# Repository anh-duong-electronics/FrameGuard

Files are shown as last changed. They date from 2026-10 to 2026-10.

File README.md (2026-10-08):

# FrameGuard — Open Leakage Voltage Monitor for Factory Machines

A small, low-cost device that watches for dangerous AC voltage leaking onto the metal frames of industrial machines — and warns people before they touch it.

An open project by **Anh Duong Electronics Viet Nam** · 🌐 **Website: [anhduongelectronics.com](https://anhduongelectronics.com)**

Firmware for the STM32C031K6T6 (ARM Cortex-M0+), 1–4 monitoring channels, LCD + LED indication, RS-485 Modbus RTU output.

| Main board | PCB + LCD | 3D-printed enclosure |
|---|---|---|
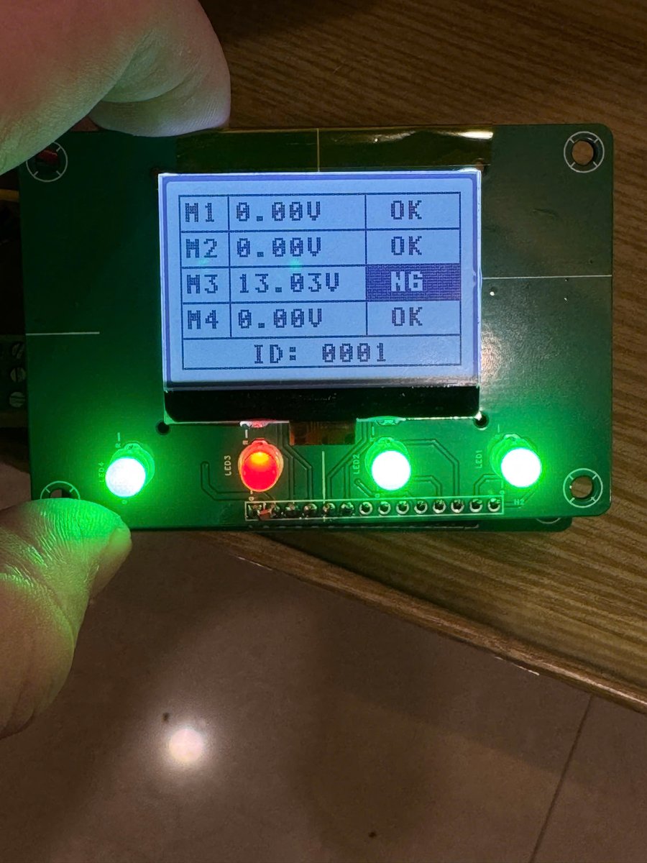
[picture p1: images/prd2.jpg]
Main board
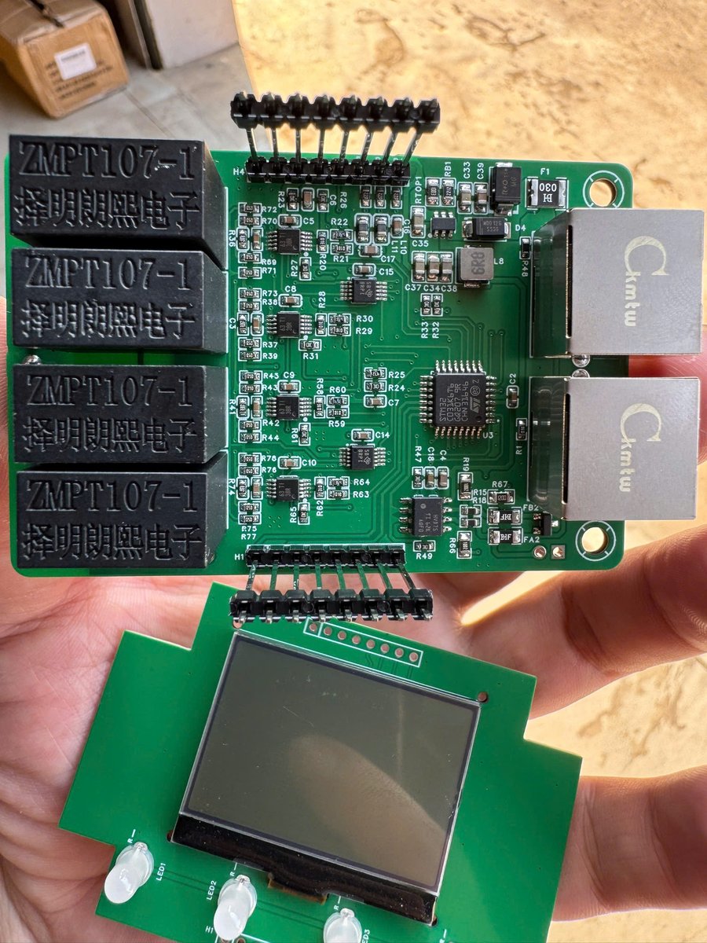
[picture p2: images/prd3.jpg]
PCB and LCD
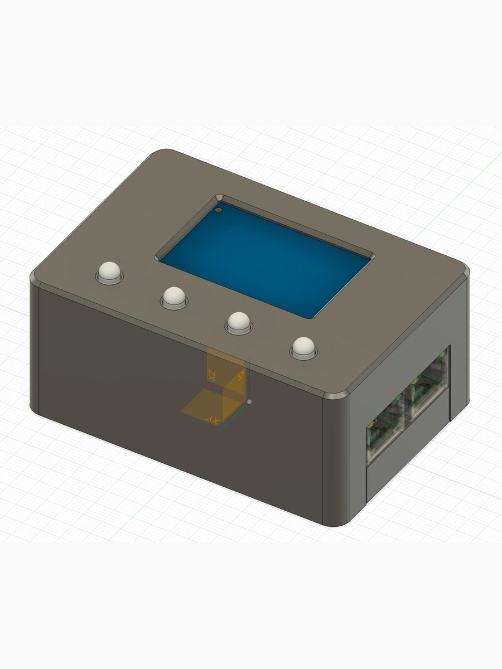
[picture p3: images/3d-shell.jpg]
Enclosure
|  |  |  |

---

## Why this project exists

Every day, millions of people work next to machines powered by mains electricity. When insulation ages, a cable is pinched, moisture gets in, or an earth connection quietly comes loose, the metal body of a machine can become live. Nothing looks different. The machine keeps running. The first person to notice may be the operator who touches it.

Electric shock in factories is preventable. Proper earthing, residual-current devices and regular inspection remain the foundation of electrical safety. But in many workplaces — especially small and medium factories — continuous monitoring of every machine frame is simply too expensive, so problems are found only during periodic checks, or after someone gets hurt.

This project started as a practical answer to that gap: **a simple box that sits on the production line, measures the voltage on each machine body continuously, and turns red the moment it becomes unsafe.** It also checks its own sensing wires, because a monitor with a broken wire that still shows "OK" is worse than no monitor at all.

I am sharing part of this work with the community because **worker safety should not depend on budget.** If this firmware helps one maintenance team find a leaking machine before a worker does, it has done its job.

### Who this is for

- Maintenance and electrical engineers who want an affordable early-warning layer on existing machines
- Makers and students learning embedded measurement, signal processing and industrial communication
- Small factories that cannot justify commercial monitoring systems for every workstation
- Anyone who wants to adapt, improve and share a safety tool

### What it does

- **Measures leakage voltage** on up to 4 machine frames, using true RMS so that distorted real-world signals (from inverters, filters, switching supplies) are not under-reported
- **Raises a clear alarm** per channel when voltage exceeds a configurable threshold — red LED and inverted "NG" on the LCD, visible from a distance
- **Detects broken or disconnected sensing wires** and reports them as a separate fault, so a silent failure is never mistaken for a safe reading
- **Reports to a central system** over RS-485 Modbus RTU, so a supervisor or SCADA/IoT gateway can watch many machines at once
- **Fails visibly**: watchdog-protected main loop, explicit INIT / ERR states, heartbeat counter on the bus

---

## ⚠️ Safety notice — please read

This is a **monitoring and early-warning aid**, not a protective device.

- It does **not** replace proper earthing, RCD/GFCI protection, insulation testing or the electrical safety regulations of your country.
- It has **not** been certified to any safety standard. Use it as an additional layer, never as the only one.
- Building, installing or connecting anything to mains-powered equipment must be done by **qualified personnel**, with the equipment isolated and following lock-out/tag-out procedures.
- The calibration table in this repository is a **placeholder**. Every build must be calibrated against a trusted true-RMS meter before it is relied on (see [Calibration](#calibration)).
- The software is provided "as is", without warranty of any kind (see [LICENSE](./LICENSE)).

If in doubt, treat every machine as live until proven otherwise.

---

## How it works (overview)

```
Machine frame ──► ZMPT107 voltage transformer ──► ADS1015 ADC (I2C) ──► STM32C031
                  (isolation + step-down)         (differential)        │
                                                                         ├─► True RMS + 50 Hz (Goertzel)
                                                                         ├─► Calibration table + per-channel K
                                                                         ├─► Threshold → OK / LEAK
                                                                         ├─► Wire check → WIRE_NG
                                                                         ▼
                                                    LCD 128×64 · LEDs · RS-485 Modbus RTU
```

- All filtering and RMS computation is done in software, so no precision analog filters are needed and the design adapts to 60 Hz grids by changing one constant.
- The device reports **true RMS** (fundamental + harmonics), matching what a true-RMS meter would show on a distorted leakage signal. The 50 Hz component is computed alongside it with the Goertzel algorithm.

See [docs/ac-measurement-algorithm.md](./docs/ac-measurement-algorithm.md) for a short explanation.

### Channel status

| Status | Meaning | LED |
|---|---|---|
| OK | Voltage below threshold, wire connected | Green |
| LEAK | Voltage above threshold | Red |
| WIRE_NG | Sensing wire broken or disconnected | Red, blinking |
| ERR | ADC / bus error | Off |
| INIT | Not yet confirmed | Off |
| DISABLED | Channel not in use (`qty=`) | Off |

---

## Hardware

- **MCU**: STM32C031K6T6 (ARM Cortex-M0+, LQFP32), 32 KB flash, 12 KB RAM, HSI 48 MHz ÷ 4 → 12 MHz
- **Sensing**: ZMPT107 voltage transformers + 2× ADS1015 12-bit ADC (I2C 0x48, 0x49), differential inputs
- **Display**: ST7567 128×64 LCD (SPI) + 4 bi-colour status LEDs
- **Field bus**: RS-485, Modbus RTU slave
- **Enclosure**: 3D-printable STL files in [`3d-shell/`](./3d-shell)
- **PCBA**: schematic, PCB layout and BOM are still under development and will be published as soon as the board has been verified to run reliably (see [Roadmap](#roadmap))

### Peripheral map

| Peripheral | Function | Pins | Notes |
|---|---|---|---|
| I2C1 | ADS1015 ADC | PA9 (SCL), PB9 (SDA) | 100 kHz |
| SPI1 | ST7567 LCD | PA1 (SCK), PA2 (MOSI), A0 = PA0, /RST = PA4, CS = GND | |
| ADC1, TIM1, GPIO | Wire check (`libwireprobe.a`) | PA5, PA7, PB0, PB1, PA8, PA15, PC6, PC15, PA6 | See `Core/Inc/wire_probe.h` |
| TIM3 | 1 µs timebase | — | Cortex-M0+ has no DWT cycle counter |
| USART1 | Modbus RTU slave | PC14 (TX), PB2 (RX), DE = PA12 | 9600 **8E1**, hardware DE, TX DMA |
| USART2 | Configuration commands (RX only) | PA3 (RX) | 115200 8N1, result shown on LCD |
| WWDG | Window watchdog | — | ~128–175 ms window |
| GPIO | 4 green/red LED pairs (active-low) | PB7/PB8, PB5/PB6, PB3/PB4, PA10/PA11 | |

---

## Getting started

### Requirements

- Arm GNU Toolchain (`arm-none-eabi-gcc`) — tested with GCC 13.2; on `PATH` or pass `make GCC_PATH=...`
- GNU Make
- SEGGER J-Link (or ST-Link / STM32CubeProgrammer)

### Build

```bash
make -j8
```

Output: `build/FrameGuard.elf` / `.hex` / `.bin` (~28.1 KB of the 30 KB application area).

- Default build is production (`DEBUG=0`).
- `make DEBUG=1` enables SEGGER RTT logging. It is built with link-time optimisation (`-flto`) so it fits the 30 KB budget (~26.8 KB).
- Run `make clean` when switching `DEBUG`.

### Flash (J-Link)

```bash
printf 'si 1\nspeed 3200\ndevice STM32C031K6\nconnect\nhalt\nloadfile build/FrameGuard.bin 0x08000000\nw4 0x40022000 0x00040600\nr\ng\nexit\n' | JLinkExe -nogui 1
```

The `w4 0x40022000 0x00040600` step clears `FLASH_ACR.EMPTY`. A blank STM32C0 latches this flag at power-up, and without clearing it every soft reset jumps into the system bootloader even though firmware is present. ST-Link / CubeProgrammer do not need this step.

### Debug logging (RTT)

Build with `make DEBUG=1`, then open JLinkRTTViewer (device `STM32C031K6`, SWD, 3200 kHz) or `JLinkRTTClient`. RTT `printf` has no `%f`; values are logged as integer millivolts.

---

## Configuration (USART2)

Send one line terminated by a newline at 115200 8N1. The result is shown on the LCD for 3 seconds and saved to flash.

| Command | Range | Purpose |
|---|---|---|
| `id=` | 1–9999 | Device ID (readable over Modbus) |
| `addr=` | 1–247 | Modbus slave address, effective immediately |
| `thr=` | 100–60000 mV | Leakage alarm threshold |
| `wire=` | 100–3000 | Wire-break detection threshold |
| `qty=` | 1–4 | Number of active channels |
| `v=` / `k1=`…`k4=` | 500–24000 mV | Per-channel calibration factor K |
| `config` | — | Show settings page on the LCD for 5 s |

## Modbus RTU

9600 bps, **8E1**, FC03 (read), FC04 (alias), FC06 (write registers 6 and 17). Standard poll: **FC03, address 1, quantity 17**.

Registers include per-channel voltage (0.01 V), per-channel status, alarm threshold, device ID, heartbeat and channel count. Full map: [docs/rs485-modbus-protocol.md](./docs/rs485-modbus-protocol.md).

## Calibration

The ZMPT107 response is not linear at low voltage, so the firmware converts readings through a multi-point table (`CAL[]` in `Core/Src/ads1015.c`) with piecewise-linear interpolation, then applies a per-channel factor K.

**The table shipped here is an illustrative linear placeholder.** To calibrate your build:

1. Build with `DEBUG=1` and connect RTT.
2. Apply known 50 Hz voltages across the range you care about, measured with a trusted true-RMS meter.
3. Record `vrms_total` for each level and replace the `CAL[]` entries (raw values must increase).
4. Rebuild with `DEBUG=0`, flash, then fine-tune each channel with `v=<mV>` while applying a known voltage.

---

## Repository layout

```
.
├── Core/
│   ├── Src/
│   │   ├── main.c            # Application, UART2 commands, Modbus register map
│   │   ├── ads1015.c         # ADS1015 driver, RMS + Goertzel, calibration table
│   │   ├── config_store.c    # Settings in the last flash page
│   │   ├── lcd_st7567.c      # ST7567 LCD driver
│   │   ├── modbus_rtu.c      # Portable Modbus RTU slave core (no HAL)
│   │   └── mb_port_usart1.c  # USART1 + DMA port for the Modbus core
│   ├── Inc/                  # Headers (wire_probe.h = wire-check API)
│   └── Lib/libwireprobe.a    # Wire-check implementation (prebuilt)
├── docs/                     # Technical notes
├── tools/                    # Python test scripts for Modbus and UART2
├── 3d-shell/                 # Enclosure STL files
└── images/
```

The wire-check implementation is distributed as a prebuilt library; everything else is open source.

## Documentation

- [AC measurement and Goertzel](./docs/ac-measurement-algorithm.md)
- [Modbus RTU protocol and register map](./docs/rs485-modbus-protocol.md)
- [System architecture](./docs/system-architecture.md)
- [ST7567 LCD notes](./docs/lcd-st7567-reference.md)
- [Test scripts](./tools/README.md)

## Development notes

- **CubeMX**: keep user code inside `/* USER CODE BEGIN/END */` blocks so regenerating from `FrameGuard.ioc` does not overwrite it.
- **Linker script**: `(READONLY)` was removed for GCC 10 compatibility; CubeMX adds it back on regeneration — remove it again or use GCC ≥ 11.
- **Watchdog**: the WWDG is always active; long operations must call `app_wwdg_kick()`.

---

## Roadmap

| Stage | Status |
|---|---|
| **Firmware** — measurement, alarms, wire check, Modbus RTU | ✅ Available in this repository |
| **3D-printed enclosure** | ✅ Available in [`3d-shell/`](./3d-shell) |
| **PCBA** — schematic, PCB layout, BOM | 🔧 In development — will be published as soon as the board has been tested and proven stable |
| **Community website** — a place to connect users, share installations, field reports and calibration data | 🗺️ Planned |
| **Real-time dashboard** — watch many machines and production lines live from one screen, with alarm history | 🗺️ Planned |

The goal is a complete, open safety kit: hardware anyone can build, firmware anyone can audit, and tools that let one person look after a whole factory floor.

---

## Contributing

Safety tools get better when more eyes look at them. Contributions are welcome, especially:

- Field reports: where you installed it, what you measured, what went wrong
- Calibration data and methods for other transformer types
- Translations of the documentation into other languages
- Hardware variants, enclosure improvements, 60 Hz validation
- Code review of the measurement and alarm logic

Please [open an issue](https://github.com/anh-duong-electronics/FrameGuard/issues) before large changes. When reporting a safety-related bug, describe the conditions clearly so others can reproduce and verify it.

## Authors

FrameGuard is developed and maintained by **Anh Duong Electronics Viet Nam** ([anhduongelectronics.com](https://anhduongelectronics.com)).

- **Lac Van Vien** — developer
- **My Nguyen** — developer

## License

The project source code is released under the [MIT License](./LICENSE), © 2026 Anh Duong Electronics Viet Nam.

Third-party components keep their original licenses:

- STM32C0xx HAL Driver (STMicroelectronics) — BSD-3-Clause, `Drivers/STM32C0xx_HAL_Driver/LICENSE.txt`
- CMSIS Device STM32C0xx (STMicroelectronics) — Apache-2.0, `Drivers/CMSIS/Device/ST/STM32C0xx/LICENSE.txt`
- CMSIS Core (Arm) — Apache-2.0, `Drivers/CMSIS/LICENSE.txt`
- SEGGER RTT — SEGGER BSD-style license, `Middlewares/Third_Party/SEGGER_RTT/LICENSE.md`

Project skeleton generated with STM32CubeMX 6.18.1 (STM32Cube FW_C0 V1.4.1).

---

*Built for the people on the factory floor. Stay safe.*

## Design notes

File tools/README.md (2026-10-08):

# Tools — Modbus RTU + UART2 config

Bench test scripts for the STM32 node (Modbus RTU slave + UART2 configuration commands). No HAL/STM32 dependency, only pyserial.

## Requirements

```bash
pip3 install pyserial
```

- USB-RS485: 9600 **8E1** (even parity)
- UART2 config: 115200 8N1, adapter TX → node RX (the node is RX-only; read results on the LCD or over Modbus)

## Scripts

| File | Purpose |
|---|---|
| `modbus_full_test.py` | FC03/04/06 test matrix: CRC, broadcast, bounds, slow feed, soak |
| `uart2_config_test.py` | Sends `id=`/`addr=`/`thr=`/`wire=`/`qty=` in one burst, verifies over Modbus |

```bash
python3 tools/modbus_full_test.py --port /dev/cu.usbserial-XXXX --addr 1
python3 tools/uart2_config_test.py --uart2 /dev/cu.usbmodemXXXX --rs485 /dev/cu.usbserial-XXXX --addr 1
```

FrameGuard register map (1-based): see [docs/rs485-modbus-protocol.md](../docs/rs485-modbus-protocol.md).

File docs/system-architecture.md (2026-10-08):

# System Architecture

## High-Level Block Diagram

```
┌─────────────────────────────────────────────────────────────────────┐
│                      STM32C031K6T6 (LQFP32)                         │
│                                                                       │
│  ┌───────────────────────────────────────────────────────────────┐  │
│  │           ARM Cortex-M0+ Core (12 MHz SYSCLK)               │  │
│  │  Flash: 32 KB  |  RAM: 12 KB  |  Stack: 0x400  |  Heap: 0x200  │
│  └───────────────────────────────────────────────────────────────┘  │
│                                                                       │
│  ┌──────────────────────────────────────────────────────────────┐   │
│  │                   Peripheral Interfaces                     │   │
│  │                                                              │   │
│  │  I2C1 (100 kHz, PA9/PB9)      ─→  ADS1015 ADC @ 0x48       │   │
│  │                                    (4 diff channels, 12-bit)  │   │
│  │  SPI1 (750 kHz, PA1/PA2)      ─→  ST7567 LCD 128×64 pixels  │   │
│  │                                    (A0=PA0, /RST=PA4, CS=GND)│   │
│  │  USART1 (9600 8E1, RS-485)    ─→  Modbus RTU slave (DE: PA12)│  │
│  │  USART2 (115200, RX-only PA3) ─→  UART2 config commands     │   │
│  │                                                              │   │
│  │  GPIO (9 outputs)             ─→  4× LED pairs + D0         │   │
│  │                                                              │   │
│  │  WWDG (~128–175 ms window)    ─→  Watchdog (active, guarded)│   │
│  │                                                              │   │
│  └──────────────────────────────────────────────────────────────┘   │
│                                                                       │
└─────────────────────────────────────────────────────────────────────┘
```

---

## Pinout Summary

### Power & Debug

| Pin | Type | Function | Notes |
|-----|---|---|---|
| VSS | GND | Ground (multiple pins) | - |
| VDD | +3.3V | Supply (multiple pins) | - |
| VDDA | +3.3V | Analog supply (ADC reference) | - |
| VREF+ | +3.3V | Internal reference (ADC) | - |
| PA13 | SWD | J-Link SWDIO (debug) | SWD @ 3.2 MHz confirmed working (HW v2, 2026-09-11). If attach fails, try 400 kHz. |
| PA14 | SWD | J-Link SWCLK (debug) | SWD @ 3.2 MHz confirmed working (HW v2, 2026-09-11). If attach fails, try 400 kHz. |

### Sensor & Measurement

| Pin | Port | Peripheral | Signal | Direction | Role | Notes |
|-----|---|---|---|---|---|---|
| PA9 | GPIOA | I2C1 | SCL | Bidirectional | ADS1015 ADC clock | 100 kHz, open-drain, 4.7 kΩ pull-up |
| PB9 | GPIOB | I2C1 | SDA | Bidirectional | ADS1015 ADC data | 100 kHz, open-drain, 4.7 kΩ pull-up |
| PA1 | GPIOA | SPI1 | SCLK | Output | ST7567 LCD clock | currently 750 kHz (lcd_init lowers the prescaler to /16) |
| PA2 | GPIOA | SPI1 | MOSI | Output | ST7567 LCD data | currently 750 kHz (lcd_init lowers the prescaler to /16) |
| PA0 | GPIOA | GPIO | A0 | Output | ST7567 LCD command/data | High=data, Low=command |
| PA4 | GPIOA | GPIO | LCD_RST | Output | ST7567 LCD hardware reset | lcd_init() configures PA4 once SPI is stable, hard-resets the LCD before the soft reset |

### Communication (RS-485)

| Pin | Port | Peripheral | Signal | Direction | Role |
|-----|---|---|---|---|---|
| PC14 | GPIOC | USART1 | TX | Output | RS-485 transmit (via PA12 DE) |
| PB2 | GPIOB | USART1 | RX | Input | RS-485 receive |
| PA12 | GPIOA | USART1 | DE | Output | Driver Enable (high = TX, low = RX) |

### USART2 configuration (RX-only)

| Pin | Port | Peripheral | Signal | Direction | Role |
|-----|---|---|---|---|---|
| PA3 | GPIOA | USART2 | RX | Input | Config commands (`id=`/`addr=`/`thr=`/`wire=`/`qty=`/`v=`/`kN=`/`config`), 115200 8N1, ISR ring. Feedback on LCD |

PA4 has been moved to GPIO for LCD /RST (see the Sensor & Measurement table).

### Status LEDs (4 green/red pairs, active-LOW, common anode)

| Pin | Port | Name | GPIO | Function | Status |
|-----|---|---|---|---|---|
| PB7 | GPIOB | L_GREEN1 | GPIO Output | Channel 1 green | Active |
| PB8 | GPIOB | L_RED1 | GPIO Output | Channel 1 red | Active |
| PB5 | GPIOB | L_GREEN2 | GPIO Output | Channel 2 green | Active |
| PB6 | GPIOB | L_RED2 | GPIO Output | Channel 2 red | Active |
| PB3 | GPIOB | L_GREEN3 | GPIO Output | Channel 3 green | Active |
| PB4 | GPIOB | L_RED3 | GPIO Output | Channel 3 red | Active |
| PA10 | GPIOA | L_GREEN4 | GPIO Output | Channel 4 green | Active |
| PA11 | GPIOA | L_RED4 | GPIO Output | Channel 4 red | Active |

Active-low LEDs (common anode), current-limited by external resistors. OK = green, leakage = red, wire broken = red heartbeat blink, ERR/INIT = off.

### Wire Check

Pins PA5, PA7, PB0, PB1 (ADC1), PA8 (TIM1_CH1) and PA15, PC6, PC15, PA6 (GPIO) are used by the
wire-break check. The implementation ships as a prebuilt library `Core/Lib/libwireprobe.a`;
see `Core/Inc/wire_probe.h` for the interface.

**TIM3**: free-running 1 µs timebase (SYSCLK 12 MHz, PSC=11, ARR=65535), replaces DWT→CYCCNT (not available on Cortex-M0+).

### Control Outputs

| Pin | Port | Name | GPIO | Notes |
|-----|---|---|---|---|
| PA0 | GPIOA | D0 | GPIO Output | ST7567 LCD A0 (command/data select) |

---

## Clock Tree

### System Clock Configuration

```
HSI (High Speed Internal Oscillator)
  │
  ├─ Frequency: 48 MHz (default, calibrated)
  │
  └─ RCC_HSI_DIV4 (prescaler /4)
       │
       └─ SYSCLK = 12 MHz
            │
            ├─ HCLK (AHB) = 12 MHz  (no divider)
            │
            ├─ PCLK1 (APB1) = 12 MHz (no divider)
            │
            └─ Peripherals:
                 I2C1: 12 MHz kernel clock (APB1)
                 SPI1: 12 MHz kernel clock (APB1)  → CubeMX prescaler /2 (6 Mbit/s); lcd_init lowers to /16 → 750 kHz
                 USART1: 12 MHz kernel clock (APB1) → 9600 bps
                 USART2: 12 MHz kernel clock (APB1) → 115200 bps
                 WWDG: 12 MHz kernel clock (APB1)  → PCLK1 / 4096 / 8 ≈ 366 Hz (~2.73 ms/count)
```

### Flash Latency

**FLASH_LATENCY_0** (0 wait cycles) — sufficient for 12 MHz operation.

### Recommended Frequency

At 12 MHz:
- Power consumption: Very low (~2–5 mA active, depending on peripherals)
- Timing budget: Adequate for sensor polling and RS-485 messaging
- Headroom: Available for future CPU-intensive tasks (DSP, FFT)

---

## Peripheral Details

### I2C1 Configuration

| Setting | Value | Notes |
|---|---|---|
| Mode | Standard (~100 kHz) | Timing: 0x00402D41 (optimized for 12 MHz) |
| Addressing | 7-bit | 8-bit addresses not used |
| Filters | Analog (enabled), Digital (0) | Noise filtering on SCL/SDA |
| Own Address | 0x00 | Slave mode not used (master only) |
| Pins | PA9 (SCL), PB9 (SDA) | Open-drain, pull-up required |

**Use case**: Read current-sensing transducers, ADCs, or other I2C sensors.

### SPI1 Configuration

| Setting | Value | Notes |
|---|---|---|
| Mode | Master | Slave mode not used |
| Direction | 2-line (MOSI+MISO) | TX-only intent in .ioc, but direction set to 2-line (conservative) |
| Data Size | 8-bit | Single byte transactions |
| Clock Polarity | 0 (CPOL=0) | Clock idles low |
| Clock Phase | 0 (CPHA=0) | Sampling on first edge |
| NSS | Soft (GPIO controlled) | No hardware NSS; PA15 or other GPIO pin managed in code |
| Baud Rate | CubeMX: PCLK1/2 = 6 Mbit/s; runtime: lcd_init sets /16 = 750 kHz | Slowed down during LCD debugging |
| Bit Order | MSB First | Standard SPI |

**Use case**: ST7567 LCD 128×64 (write-only; A0=PA0, /RST=PA4, CS tied to GND).

### USART1 (RS-485) Configuration

| Setting | Value | Notes |
|---|---|---|
| Baud Rate | 9600 bps | Industrial RS-485 |
| Data Bits | 8 | |
| Parity | **Even (8E1)** | Standard Modbus RTU |
| Stop Bits | 1 | |
| Mode | Asynchronous | Half-duplex, DE=PA12 |
| RS-485 Mode | Enabled | Hardware DEM, compatible with TX DMA |
| FIFO | Disabled | RX 1 byte RDR → ISR bare-register |
| Pins | PC14 (TX), PB2 (RX) | |

**Use case**: Modbus RTU slave (`modbus_rtu.c` + `mb_port_usart1.c`). FC03/04/06, map 1-based — [rs485-modbus-protocol.md](./rs485-modbus-protocol.md).

After `mb_init`: **no HAL UART TX API on USART1**. TX = DMA1 ch1 (DMAMUX req 51), polls TCIF. The RX ISR marks gaps ≥ 5 ms. NVIC USART1 priority 1.

### USART2 (Config Commands RX-only) Configuration

| Setting | Value | Notes |
|---|---|---|
| Baud Rate | 115200 bps | Configuration command interface |
| Data Bits | 8 | Standard byte format |
| Parity | None | No error detection |
| Stop Bits | 1 | Standard frame format |
| Mode | Receive only | PA3 RX; PA4 GPIO freed for LCD /RST |
| FIFO | Disabled | CubeMX default |
| Pins | PA3 (RX) | RX-only, no TX |

**Use case**: RX-only technician commands (`id=`/`addr=`/`thr=`/`wire=`/`qty=`/`v=`/`kN=`/`config`). `USART2_IRQHandler` → 32-byte ring (NVIC priority 2, below Modbus). `poll_serial()` only drains the ring + parses. LCD feedback for 3 s. Details: [rs485-modbus-protocol.md](./rs485-modbus-protocol.md).

### Window Watchdog (WWDG) Configuration

| Setting | Value | Notes |
|---|---|---|
| Prescaler | 8 (PCLK1 / 4096 / 8) | Watchdog clock = 12 MHz / 4096 / 8 ≈ 366 Hz (~2.73 ms/count) |
| Window | 80 (0x50) | Refresh allowed only when counter < 80 |
| Counter | 127 (0x7F) | Initial/reload value; reset fires when counter drops below 64 (0x40) |
| EWI (Early Wakeup) | Disabled | No interrupt before reset |
| Timeout | ~175 ms | (127 − 63) × 2.73 ms |
| Refresh window | ~131–175 ms after reload | Counter 79→64: window is open for ~44 ms |

**Critical caveats**:
- Code calls `app_wwdg_kick()` (main.c) everywhere: it only refreshes when the counter < Window and ignores early calls. Since the valid window is only ~44 ms wide, **two consecutive kick calls must be less than ~44 ms apart**, otherwise the first may be ignored (too early) and the next may already be past 175 ms → reset.
- Lesson learned: a blocking UART transmit of ~50 ms without kicking caused a reset on every measurement loop. Every long blocking operation (slow UART, LCD, delays) must be split into chunks with kicks in between; Modbus TX now uses background DMA.
- The RTT boot log prints `rst=... WWDG` when `RCC_FLAG_WWDGRST` is set, so watchdog resets are visible in the log.

---

## Memory Layout

### Flash (32 KB, 0x08000000–0x0800_7FFF)

```
0x08000000  ┌─────────────────────┐
            │  Vector Table       │  0x0C0 bytes (48 vectors)
            │  (.isr_vector)      │
0x080000C0  ├─────────────────────┤
            │                     │
            │  Code + Constants   │
            │  (.text)            │
            │  (CubeMX HAL ~28 KB)│
            │  (User code ~2–4 KB)│
            │                     │
0x0800_7FFF └─────────────────────┘  End of Flash
```

**Available for code**: 30 KB (page 15 = config_store). Production build (DEBUG=0) text+data **~28.1 KB**, RAM bss ~5.5 KB. DEBUG=1 (RTT, built with `-flto`) ~26.8 KB. Tight headroom (~1.9 KB in production).

### RAM (12 KB, 0x20000000–0x2000_2FFF)

```
0x20000000  ┌─────────────────────┐
            │  Initialized Data   │
            │  (.data)            │
            │  (HAL + User ~0.5 KB)
            ├─────────────────────┤  data_end
            │  Uninitialized Data │
            │  (.bss)             │
            │  (Global buffers, ~1 KB)
            ├─────────────────────┤  bss_end
            │  Heap (bottom-up)   │
            │  (Reserved 0x200 B) │  ← Growth direction
            ├─────────────────────┤  heap_base
            │  ...free...         │
            │                     │
            ├─────────────────────┤  stack_base
            │  Stack (top-down)   │
            │  (Reserved 0x400 B) │  ← Growth direction
0x2000_2FFF └─────────────────────┘  End of RAM (12 KB)
```

**Safe allocation**:
- `.bss` + `.data`: ~1.5 KB
- Stack: 0x400 bytes (1 KB)
- Heap: 0x200 bytes (0.5 KB)
- **Free for user buffers**: ~10 KB

---

## Interrupt Priority Model

All interrupts use **Cortex-M0+ NVIC** (16 priority levels, no sub-priorities in M0+).

### Default ISR Priorities (HAL configured)

| Handler | Vector | Priority | Type |
|---|---|---|---|
| Non-maskable Interrupt (NMI) | -14 | Highest | Fault |
| Hard Fault | -13 | Very High | Fault |
| System Tick (SysTick) | 15 | 0 (default) | Periodic |
| USART1 | 6 | 1 | Modbus RX ISR (mb_port_usart1) |
| USART2 | 7 | 2 | Config RX ISR (ring, below Modbus) |
| I2C1 (Events + Errors) | 23–24 | 0 (default) | Peripheral |
| SPI1 | 25 | 0 (default) | Peripheral |

USART1 (priority 1) preempts USART2 (priority 2) so config commands never cause lost Modbus bytes.

---

## Power Considerations

### Operating Supply

- **VDD**: +3.3 V (single supply)
- **VDDA**: +3.3 V (same as VDD, can be shared with filter capacitor)
- **Decoupling**: 100 nF (typical for 32-pin QFP)

### Current Consumption (Estimate)

At 12 MHz, running all peripherals:

| Component | Current (mA) |
|---|---|
| Core (M0+, 12 MHz) | ~2–3 |
| I2C (idle, pull-ups) | ~0.1–0.5 |
| SPI1 (idle) | <0.1 |
| USART1 (idle) | <0.1 |
| USART2 (idle) | <0.1 |
| GPIO (all outputs low) | <0.1 |
| **Total (idle)** | **~2–4 mA** |

**Note**: Actual power depends on:
- Sensor power draw (external)
- LED brightness (if enabled)
- Bus activity (RS-485 driver)
- Flash accesses

---

## System Initialization Sequence

```
Power-on Reset
    ↓
startup_stm32c031xx.s (Reset Handler)
    ↓
SystemInit() [system_stm32c0xx.c]
    └─ Set flash latency
    └─ Configure clock (HSI → 12 MHz)
    └─ Set NVIC priority defaults
    ↓
main()
    └─ HAL_Init()
         └─ Configure SysTick (1 ms tick)
         └─ Set default NVIC priorities
    └─ SystemClock_Config()  [already done, safety check]
    └─ MX_GPIO_Init()
    └─ MX_I2C1_Init()
    └─ MX_SPI1_Init()
    └─ MX_USART1_UART_Init()
    └─ MX_USART2_UART_Init()  [RXNEIE, NVIC prio 2]
    └─ MX_ADC1_Init()  [ADC1 sequencer, SamplingTimeCommon1 79.5 cycles]
    └─ MX_TIM1_Init()  [TIM1 PWM at PA8 for wire check]
    └─ MX_TIM3_Init()  [TIM3 1 µs timebase]
    └─ MX_WWDG_Init()
    └─ APP_LOG_INIT()  [SEGGER RTT init if DEBUG=1]
    └─ config_load()  [layout v4: id/addr/qty/thr/wire/K]
    └─ probe_set_open_mvpp(g_cfg.wire_mvpp)
    └─ mb_init()  [Modbus RTU, no HAL TX on USART1]
    └─ ads_probe() × 2  [probe ADS1015 @ 0x48, 0x49]
    └─ probe_init()  [wire check]
    └─ lcd_init()  [SPI + PA4 hard reset]
    ↓
Main Loop (~1 Hz per group)
    └─ for each channel 0..3: if i ≥ ch_count → LED off, clear data, skip
    └─ probe_measure() + probe_update()
    └─ ads_measure_channel(); vac = calibration_table × K[i]
    └─ mb_poll() between channels (hooks in ads1015 + main)
    └─ lcd_show_channels()  [disabled channels blank; 5 s config page after the config command]
    └─ poll_serial()  [drain the USART2 ring]
    └─ app_wwdg_kick()
    ↓
(Continues at ~1 Hz; WWDG fires reset if not refreshed ~131–175 ms)
```

---

## Flashing & Debugging

### J-Link Programming with FLASH_ACR.EMPTY Workaround

**Issue**: When programming a blank STM32C031 chip via J-Link, the MCU may fail to boot firmware after reset, instead jumping to the system bootloader (PC = 0x1FFF0CDE). Cause: FLASH_ACR.EMPTY flag is latched at power-on when flash is blank; soft reset (SYSRESETREQ) does not reload option bytes, so every reset—including HAL_Delay softresets—stays in bootloader.

**Solution**: After loading firmware via `loadfile`, issue J-Link command `w4 0x40022000 0x00040600` to clear the EMPTY flag. This writes the correct FLASH_ACR value (bits EMPTY=0, PRFTEN=0, DUF=1) before disconnecting.

```bash
JLinkExe -nogui <<EOF
si 1
speed 3200
device STM32C031K6
connect
halt
loadfile build/FrameGuard.bin 0x08000000
w4 0x40022000 0x00040600    # ← Clear FLASH_ACR.EMPTY before reset
r
g
exit
EOF
```

**Note**: ST-Link and CubeProgrammer do not exhibit this issue because they use hardware reset (NRST) instead of SYSRESETREQ, which automatically handles the flag reload.

**SWD Speed**: `speed 3200` (3.2 MHz) is stable for flashing and RTT on this board; if attach fails, drop to 400 kHz.

---

## External Connections

### ADS1015 ADC (I2C @ 0x48)

```
STM32C031K6T6 (PA9=SCL, PB9=SDA)
         │
    [I2C @ 100 kHz]
         │
   ┌─────┴─────┐
   │ ADS1015   │
   │ (ADDR=GND)│
   │ 12-bit    │
   │ 4-channel │
   └─────┬─────┘
         │
    [AIN0–AIN3: 2 differential channels from ZMPT107 transformers; second IC @ 0x49 (ADDR=VDD)]
```

**Note**: 4.7 kΩ pull-ups on SCL/SDA to 3.3V required.

### ST7567 LCD (SPI, currently 750 kHz)

```
STM32C031K6T6
  ├─ PA1 (SCLK) ──────────┐
  ├─ PA2 (MOSI) ──────────┤
  ├─ PA0 (A0)   ──────────├─ ST7567 LCD
  ├─ PA4 (/RST) ──────────┤  128×64 pixels
  └─ CS (GND)   ──────────┤  COG12864-14-1
                          │
                [V0–XV0, VG–VSS:]
                 0.1–1 µF X7R caps
                 (booster supply)
```

**Hardware changes (HW v2)**:
- LCD /RST pin now connected to GPIO PA4
- `lcd_init()` configures PA4 as output and hard-resets the LCD (~10 µs pulse) **after SPI is stable** (SCK/MOSI at defined levels)
- Why not NRST: if the LCD powers up before the MCU it sees a floating (undefined) SCK → byte slip. A self-configured PA4 GPIO reset guarantees the timing.
- The firmware also sends a soft reset (0xE2 command) in the init routine

**Hardware note (resolved)**: LCD V0 supply (booster capacitor voltage) was collapsing due to undersized booster caps. Fixed with 0.1–1 µF X7R C0G capacitors at V0–XV0 and VG–VSS.

### RS-485 Network (USART1)

```
┌───────────────────────────────────────┐
│  Central Monitoring System            │
│  (RS-485 Master)                      │
└───────────────────┬───────────────────┘
                    │
        ┌───────────┴──────────┐
        │   Twisted Pair (A, B)│
        │   (120 Ω terminator) │
        └───────────┬──────────┘
                    │
     [PA12 DE]  [PC14 TX/PB2 RX]
         │           │
    ┌────┴───────────┘
    │
STM32C031K6T6 (RS-485 Slave)
```

USART1 is **in use**: Modbus RTU slave. The master polls FC03 addr 1 qty 17; recommended timeout 500 ms over USB-RS485.

---

**For register-level details, consult the [STM32C031 Datasheet](https://www.st.com/en/microcontrollers/stm32c031k6.html).**  
**For AC measurement algorithm (Goertzel, calib, RMS), see [AC Measurement Algorithm](./ac-measurement-algorithm.md).**

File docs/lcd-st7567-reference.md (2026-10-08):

# LCD ST7567 Reference

Reference notes for the ST7567 128x64 COG LCD module, reusable in other STM32 projects.

## Panel

- **IC**: ST7567 (controller on glass)
- **Panel**: Xuyang COG12864-14-1, 1.9", 128x64 pixels, monochrome
- **Interface**: SPI (mode 0: CPOL=0, CPHA=0), MSB first
- **Supply**: 3.3 V logic, internal booster generates V0 for the LCD
- **Duty/Bias**: 1/65 duty, 1/9 bias (`CMD_BIAS_1_9 = 0xA2`)

## Hardware connections

| LCD pin | Function | Notes |
|---|---|---|
| SCK | SPI clock | SPI1_SCK |
| SDA/MOSI | SPI data | SPI1_MOSI |
| A0 | Command/data select | GPIO output: LOW = command, HIGH = data |
| /RST | Hardware reset | GPIO output: active low, 10 ms pulse |
| CS | Chip select | **Tied to GND** (always selected) |
| V0, XV0 | Booster output | Booster capacitor between the two pins |
| VG, VSS | Booster ground | Booster capacitor between the two pins |

### Booster capacitors (IMPORTANT)

V0–XV0 and VG–VSS need **X7R 0.1–1 µF** capacitors (ceramic, low ESR). The wrong capacitor causes LCD flicker:
- Wrong value or type → V0 unstable → the whole display flickers every ~200 ms
- SPI bursts interfering with the booster → V0 dips briefly → random flashes during fast updates
- Symptom: content is correct and not garbled, but blinks off and recovers by itself

**Diagnosis**: if a static test (no SPI after boot) still flickers → definitely the capacitors. If it only flickers during updates → marginal capacitors, SPI bursts make V0 dip.

## Driver configuration

```c
/* lcd_st7567.h */
#define LCD_WIDTH      128
#define LCD_HEIGHT     64
#define LCD_PAGES      (LCD_HEIGHT / 8)   /* 8 pages */
#define LCD_X_OFFSET   0                  /* DDRAM has 132 columns, panel starts at 0 */

#define LCD_CONTRAST   10       /* EV 0..63, EV=10 gives good contrast on this panel */
#define LCD_RR         0x25     /* Regulator ratio 5.5 (0x20..0x27 → 3.0..6.5) */
#define LCD_SEG_REMAP  0xA0     /* 0xA0 normal, 0xA1 mirror horizontal */
#define LCD_COM_DIR    0xC8     /* 0xC0 normal, 0xC8 mirror vertical */
```

## Initialisation sequence

```
1. Configure the /RST GPIO (output push-pull)
2. Hardware reset: /RST LOW 10 ms → HIGH 10 ms
3. Kick the WWDG (if used)
4. Soft reset (0xE2), delay 10 ms
5. Display OFF (0xAE)
6. Start line = 0 (0x40)
7. SEG remap (0xA0 or 0xA1)
8. COM direction (0xC0 or 0xC8)
9. Bias 1/9 (0xA2)
10. Display normal (0xA6, not inverted)
11. All pixels off (0xA4)
12. Power up booster → regulator → follower:
    - 0x2C, delay 50 ms, kick WWDG
    - 0x2E, delay 50 ms, kick WWDG
    - 0x2F, delay 10 ms, kick WWDG
13. Regulator ratio (LCD_RR)
14. EV set: 0x81, LCD_CONTRAST
15. Booster ratio: 0xF8, 0x00
16. Clear the framebuffer, update the display
17. Display ON (0xAF)
```

Total init time: ~140 ms (mostly the power-up sequence). With a WWDG (~131 ms window), kicks must be interleaved between delays.

## Framebuffer & rendering

- Framebuffer: `uint8_t fb[8][128]` — 8 pages × 128 columns = 1024 bytes
- Each page = 8 vertical pixels, LSB = top pixel
- Set pixel: `fb[y >> 3][x] |= (1u << (y & 7))`
- Clear pixel: `fb[y >> 3][x] &= ~(1u << (y & 7))`

### Updating the display

```c
void lcd_update_pages(uint8_t page0, uint8_t page1)
{
  for (page = page0; page <= page1; page++) {
    lcd_set_page_col(page, 0);     /* set page + column 0 */
    lcd_data_buf(fb[page], 128);   /* SPI transmit 128 bytes */
  }
}
```

- `lcd_update()` = update all 8 pages
- Partial updates (`lcd_update_pages(2, 5)`) reduce SPI traffic when only a middle region changes

### A0 settle time

CS is tied to GND, so there is no CS toggle between command and data. A0 must settle before the first SCLK edge:

```c
static void lcd_a0(GPIO_PinState s)
{
  lcd_spi_ready();                    /* wait for SPI to finish */
  HAL_GPIO_WritePin(A0_PORT, A0_PIN, s);
  for (volatile uint32_t i = 0; i < 48U; i++) {}  /* settle delay */
}
```

48 loop iterations @ 12 MHz ≈ 4 µs, enough for the ST7567.

## Font

- 5x7 font, column-major, LSB = top pixel
- ASCII 0x20..0x7E (space..tilde)
- Bold: each column is drawn as 2 adjacent pixels (col, col+1)
- Advance: 8 px per character (5 data + 1 bold + 2 spacing)

### Inverted text (white on black)

Used for inverted headers or blinking:

```c
void lcd_draw_char_inv(int x, int y, char c)
{
  /* Same as lcd_draw_char but lcd_set_pixel(..., 0) instead of 1 */
  /* Requires: the background area is already filled black */
}
```

Pattern: `lcd_fill_rect(x, y, w, h, 1)` then `lcd_draw_string_inv(...)`.

## Drawing primitives

| Function | Description |
|---|---|
| `lcd_clear()` | Clear the framebuffer (memset 0) |
| `lcd_update()` | Write the whole framebuffer to the display |
| `lcd_set_pixel(x, y, color)` | Set/clear one pixel |
| `lcd_draw_hline(x, y, w, color)` | Horizontal line |
| `lcd_draw_vline(x, y, h, color)` | Vertical line |
| `lcd_draw_rect(x, y, w, h, color)` | Rectangle outline |
| `lcd_fill_rect(x, y, w, h, color)` | Filled rectangle |
| `lcd_fill_circle(cx, cy, r, color)` | Filled circle |
| `lcd_draw_char(x, y, c)` | One character (bold, 8 px advance) |
| `lcd_draw_string(x, y, s)` | String |
| `lcd_draw_char_inv(x, y, c)` | Inverted character (white on black) |
| `lcd_draw_string_inv(x, y, s)` | Inverted string |
| `lcd_draw_uint(x, y, v)` | Unsigned integer |

## SPI speed

- CubeMX default: `SPI_BAUDRATEPRESCALER_2` → 6 MHz @ 12 MHz Fsys
- Debug prescaler in `lcd_init()`: `SPI_BAUDRATEPRESCALER_16` → 750 kHz
- Once stable, remove the override in `lcd_init()` to return to 6 MHz

## Debugging LCD flicker

1. **Static test**: draw once, then loop doing nothing → rules out software
2. **Counter test**: update every 1 s vs 100 ms → if flicker rate scales, SPI is triggering V0 dips
3. **Uptime counter**: if the counter keeps running through a flicker → the MCU did not reset → electrical issue
4. **Correct content after a flicker**: V0 sag (self-recovering), not SPI corruption (which would need DISPLAY_ON to recover)
5. **All-pixels-on test** (`0xA5`): bypasses RAM, tests the booster directly

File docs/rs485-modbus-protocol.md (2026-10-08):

# RS-485 Modbus RTU Protocol (FrameGuard node)

Single source of truth for the node firmware, the test scripts and the Modbus master. The map is **1-based**: addr 1 = VAC P1.

## Serial

| | |
|---|---|
| Baud rate | 9600 bps |
| Framing | **8E1** (even parity) |
| Slave address | 1–247, default 1; UART2 command `addr=` |
| Broadcast 0 | Strictly silent |
| Functions | **FC03** read; FC04 alias with the same data (optional); FC06 write single register (addr 6, 17) |
| Request | Exactly **8 bytes**. Frame ≠ 8 bytes → silent |

## Register map

`reg_count = 18`. Standard read: **FC03 addr 1 qty 17** (registers 1–17, including wire threshold + channel count).

| Addr | Name | Unit | Notes |
|---|---|---|---|
| 0 | reserved | — | reads 0 |
| 1–4 | VAC P1–P4 | 0.01 V | I2C error → `0xFFFF`; valid values clamp at `0xFFFE`. Disabled channel (`qty=`) → 0 |
| 5 | DEVICE_ID | — | 1–9999, device identifier |
| 6 | ALERT_THRESHOLD | mV | Active value in RAM. **Writable via FC06** (100–60000), not saved to flash |
| 7 | FW_HEARTBEAT | — | +1 per scan loop |
| 8–11 | CH_STATUS P1–P4 | enum | 0 INIT, 1 OK, 2 LEAK, 3 WIRE_NG, 4 ERR, **5 DISABLED** |
| 12–15 | WIRE_MVPP P1–P4 | — | wire-check reading (diagnostics). Disabled channel → 0 |
| 16 | WIRE_THRESHOLD | — | read-only; set with `wire=` (100–3000) |
| 17 | CH_COUNT | — | **Writable via FC06** (1–4), saved to flash — same as `qty=`. Channel i ≥ CH_COUNT: not measured, LED off, LCD blank, st=5 |

VAC < 0 ⇔ CH_STATUS = 4. VAC×1000 > ALERT_THRESHOLD ⇔ CH_STATUS = 2 (the same `is_leak()` used by LEDs/LCD).

FC06 to register 6 only changes RAM (a restart returns to the flash value). The persistent value is the UART2 `thr=` command (flash); a master that wants its own threshold should compare register 6 on every poll and re-write it with FC06 when it differs.

## Exceptions / silence

| Situation | Node |
|---|---|
| Unknown FC | exception 0x01 |
| addr/qty out of range, qty=0, FC06 addr ∉ {6, 17} | exception 0x02 |
| FC06 value out of range (reg 6: 100–60000; reg 17: 1–4) | exception 0x03 |
| Wrong address, bad CRC, frame ≠ 8 bytes, PE/FE/NE | silent |
| Request received > 150 ms ago and not yet answered | dropped silently |

## Timing

- One 8E1 character = 11 bits → ≈1.15 ms/byte. An FC03 17-register response = 39 bytes ≈ 45 ms.
- Frames complete **by length** (8 bytes). A gap ≥ 5 ms in the ISR marks a new frame boundary (USB-RS485 adapters often insert 1–16 ms gaps).
- Background TX DMA, hardware DE (DEM).
- Poll ≥ 1 s per node. USB-RS485 tool timeout: **500 ms** (measured Python+FTDI ~300 ms). Direct-UART master: 200 ms is enough unless the LCD stalls; 2 retries.
- The UART2 `config_save` flash erase takes ~22–40 ms: at most 1 request is lost, covered by master retries.

## UART2 — technician commands

USART2 **RX-only** on PA3, 115200 8N1. Feedback on the LCD for 3 s (inverted). Saved to flash immediately (magic in the last double-word). RX is interrupt-driven into a 32-byte ring, so a whole line can be sent in one burst (paste/script).

| Command | Range | Meaning |
|---|---|---|
| `id=` | 1–9999 | Device identifier (DEVICE_ID) |
| `addr=` | 1–247 | Modbus address, effective immediately |
| `thr=` | 100–60000 mV | Leakage threshold (flash + RAM) |
| `wire=` | 100–3000 | Wire-break detection threshold, shared by 4 channels |
| `qty=` | 1–4 | Number of channels in the machine group |
| `v=` | 500–24000 mV | Calibrate K on all enabled channels: K = V_ref / VAC_untrimmed, K ∈ 0.5..2.0 |
| `k1=`…`k4=` | 500–24000 mV | Calibrate K on one channel, same guard |
| `config` | (no argument) | Settings page on the LCD for 5 s |

There is no `show` command (no TX). Measured VAC = ADS calibration table × K[i], K defaults to 1.0.

Flashing firmware with config layout v4 (`CFG_MAGIC 0xAC05C1D4`) **erases older configs** — the technician must set them again.

## Example frames (slave 1)

```
FC03 read 17 regs:   01 03 00 01 00 11 D4 06
FC06 threshold 3000: 01 06 00 06 0B B8 6E 89   → echoed on success
FC06 channels = 2:   01 06 00 11 00 02 58 0E   → echoed on success, saved to flash
qty=125:             01 04 00 01 00 7D …       → exception 0x02
```

## Test scripts

See [tools/README.md](../tools/README.md).

- `tools/modbus_full_test.py` — 27 PASS / 0 FAIL on a real bus (1000 consecutive polls, 0 WWDG resets).
- `tools/uart2_config_test.py` — id/addr/thr/wire/qty PASS. Calibration `v=`/`kN=` needs an AC source and is not covered by the script.

## Threat model

The RS-485 bus is unauthenticated. Defences: strict CRC/length/range checks, no broadcast, FC06 only changes RAM; the master should check DEVICE_ID against an expected addr→id table.

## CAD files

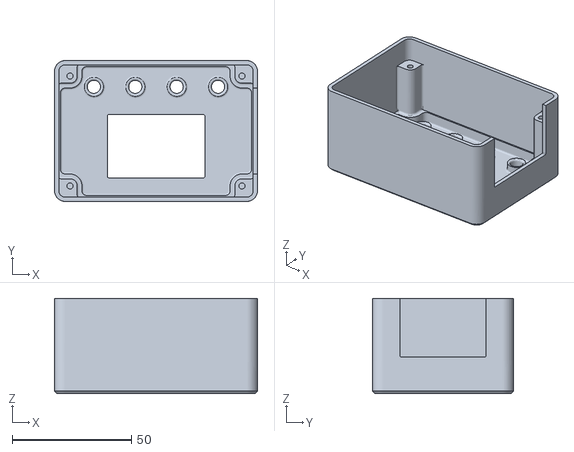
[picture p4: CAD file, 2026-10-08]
3d-shell/part2.stl
85.0 x 59.0 x 39.8

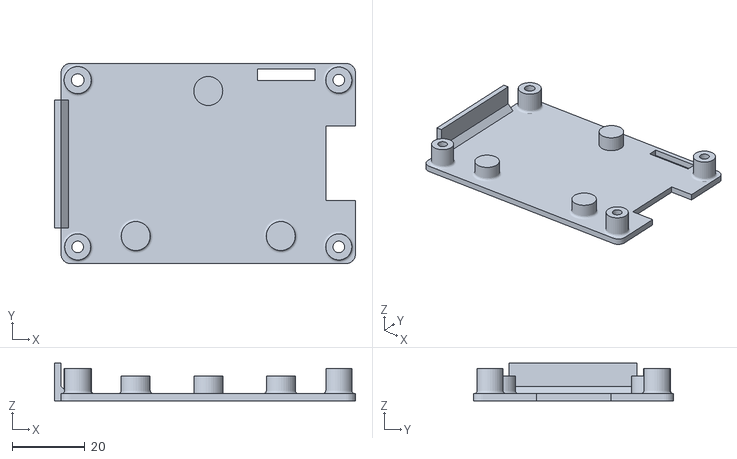
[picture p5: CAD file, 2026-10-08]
3d-shell/part1.stl
83.0 x 55.2 x 10.4

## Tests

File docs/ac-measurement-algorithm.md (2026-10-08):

# AC Measurement and the Goertzel Algorithm

A short description of how the device measures AC leakage voltage. Source code: `Core/Src/ads1015.c`.

## Measurement chain

```
AC leakage voltage
    │
    ▼
ZMPT107 (voltage transformer)  ← step-down, isolation
    │
    ▼
ADS1015 (ADC, I2C)             ← differential measurement, digitising
    │
    ▼
STM32 (software)               ← RMS, extract the 50 Hz component
    │
    ▼
Calibration table              ← convert to the actual voltage
    │
    ▼
LCD / LED / RS-485
```

The analog front end only steps down and digitises. All frequency filtering and RMS computation is done in
software, so no analog filter is needed, and moving to a 60 Hz grid only means changing one constant.

## Sampling

Each channel is sampled continuously over a short window containing several whole mains cycles.
The mean of the samples (the DC component, from ADC offset) is subtracted before processing.

## Two ways to compute RMS

| Value | Computed by | Meaning |
|---|---|---|
| Full-band RMS | square root of the mean of squared samples | 50 Hz + harmonics + noise, like a true-RMS meter |
| 50 Hz RMS | Goertzel algorithm | Only the component at the mains frequency |

The device reports leakage using **full-band RMS**. Real leakage voltages (through EMI filter capacitors,
inverters) are often distorted and rich in harmonics; using only 50 Hz would read lower than a true-RMS meter.
The 50 Hz RMS is still computed for reference.

## The Goertzel algorithm

Goertzel answers the question: "how large is the component at **one specific frequency** in this signal?"
without computing the whole spectrum like an FFT.

Idea: compare the signal with a reference 50 Hz sine wave. The 50 Hz component is in step with it and
accumulates into a large value; harmonics and noise are out of step and cancel themselves out.

Goertzel does this with a recursive loop using only a few state variables and no sine table, which suits
a RAM-constrained microcontroller such as the Cortex-M0+. The target frequency is recomputed from the actual
sample rate of each measurement, so the result does not drift when the I2C speed varies.

## Calibration

The ZMPT107 response is not linear at low voltage, so the firmware converts readings through a **multi-point
calibration table** (piecewise-linear interpolation) rather than a single scale factor.

Small differences between transformers are compensated by a **per-channel factor K**, stored in flash.
Set K by applying a reference voltage to the channels and sending `v=<mV>` (or `k1=`…`k4=`) over UART2;
the firmware computes and saves it.

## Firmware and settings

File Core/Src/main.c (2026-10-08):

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
/* Includes ------------------------------------------------------------------*/
#include "main.h"

/* USER CODE BEGIN Includes */
#include <string.h>
#include <stdbool.h>
#include "ads1015.h"
#include "config_store.h"
#include "lcd_st7567.h"
#include "app_debug.h"
#include "wire_probe.h"
#include "modbus_rtu.h"
#include "mb_port_usart1.h"
/* USER CODE END Includes */

/* USER CODE BEGIN PD */
#define VAC_ZERO_V          0.05f     /* V_AC below this is treated as 0 — less decimal noise on the LCD */
#define PROBE_SETTLE_MS     3         /* wait for the switch to return to measure position before reading ADS */
#define LED_ENABLE          1         /* 1 = status LEDs on, 0 = off */
#define PRINT_INTERVAL_MS   1000UL    /* LCD + RTT log update period */
#define RS485_OFFLINE_MS    10000UL
#define CFG_MSG_MS          3000UL    /* how long a config-command result stays on the LCD ID row */
#define MB_REG_COUNT        18        /* map 1-based: addr 1..17, addr 0 reserved — docs/rs485-modbus-protocol.md */
#define LCD_PAGE_INTERVAL   5000UL
/* USER CODE END PD */

ADC_HandleTypeDef hadc1;

I2C_HandleTypeDef hi2c1;

SPI_HandleTypeDef hspi1;

TIM_HandleTypeDef htim1;
TIM_HandleTypeDef htim3;

UART_HandleTypeDef huart1;
UART_HandleTypeDef huart2;

WWDG_HandleTypeDef hwwdg;

/* USER CODE BEGIN PV */
static app_config_t g_cfg = {
  .device_id = 1001, .modbus_addr = 1, .ch_count = ADS_NUM_CHANNELS, .alert_mv = 5000,
  .wire_mvpp = PROBE_OPEN_MVPP_DEFAULT, .k_factor = { 1.0f, 1.0f, 1.0f, 1.0f },
};

/* ACTIVE alarm threshold (mV). Boots from g_cfg.alert_mv; FC06 overrides it
 * at runtime (RAM-only — the persistent value is managed by the master/UART2). Every threshold
 * comparison must go through is_leak() — never compare directly, to avoid mixing V and mV. */
static uint16_t g_alert_mv = 5000;
static uint16_t mb_heartbeat = 0;

static uint32_t last_rs485_poll  = 0;
static bool     lcd_page         = false;
static uint32_t last_page_switch = 0;

static float   vac_ch[ADS_NUM_CHANNELS] = { 0 };
static float   raw_ch[ADS_NUM_CHANNELS] = { 0 };   /* vrms_total — used for table calibration */
static float   vac_uncal[ADS_NUM_CHANNELS] = { 0 }; /* VAC before factor K — source for v=/kN= calibration */

/* Per-channel calibration factor; old configs (previous layout) stored 0 → treated as 1.0 */
static float kf(int i)
{
  float k = g_cfg.k_factor[i];
  return (k > 0.0f) ? k : 1.0f;
}
static probe_state_t wire_ch[ADS_NUM_CHANNELS];     /* confirmed wire-check result */
static uint16_t      wire_mvpp[ADS_NUM_CHANNELS];   /* latest wire-check amplitude, diagnostics */

/* Per-channel verdict for LED/LCD/RS485. Fixed numeric codes, used on the wire. */
typedef enum {
  CH_INIT = 0,   /* wire not yet confirmed after startup */
  CH_OK,         /* wire connected, no leakage */
  CH_LEAK,       /* leakage (LCD "NG") */
  CH_WIRE_NG,    /* sensing wire broken / open */
  CH_ERR,        /* ADS1015 not responding */
  CH_DISABLED,   /* channel beyond the configured count (qty=) — not measured, LED off, LCD blank */
} ch_status_t;

/* A machine group has 1..4 channels (qty= command): only P1..Pn are active */
static bool ch_enabled(int i) { return i < g_cfg.ch_count; }
static bool    wwdg_started = false;

#if LED_ENABLE
static GPIO_TypeDef *const LED_G_PORT[ADS_NUM_CHANNELS] =
  { L_GREEN4_GPIO_Port, L_GREEN3_GPIO_Port, L_GREEN2_GPIO_Port, L_GREEN1_GPIO_Port };
static const uint16_t LED_G_PIN[ADS_NUM_CHANNELS] =
  { L_GREEN4_Pin, L_GREEN3_Pin, L_GREEN2_Pin, L_GREEN1_Pin };
static GPIO_TypeDef *const LED_R_PORT[ADS_NUM_CHANNELS] =
  { L_RED4_GPIO_Port, L_RED3_GPIO_Port, L_RED2_GPIO_Port, L_RED1_GPIO_Port };
static const uint16_t LED_R_PIN[ADS_NUM_CHANNELS] =
  { L_RED4_Pin, L_RED3_Pin, L_RED2_Pin, L_RED1_Pin };
/* Desired LED state — written by the main loop, read by the SysTick ISR to update outputs */
static volatile bool g_green_on[ADS_NUM_CHANNELS] = { 0 };
static volatile bool g_red_on[ADS_NUM_CHANNELS]   = { 0 };
static volatile bool g_red_hb[ADS_NUM_CHANNELS]   = { 0 };   /* red heartbeat blink: wire broken */
#endif
/* USER CODE END PV */

void SystemClock_Config(void);
static void MX_GPIO_Init(void);
static void MX_I2C1_Init(void);
static void MX_SPI1_Init(void);
static void MX_USART1_UART_Init(void);
static void MX_USART2_UART_Init(void);
static void MX_WWDG_Init(void);
static void MX_ADC1_Init(void);
static void MX_TIM1_Init(void);
static void MX_TIM3_Init(void);
/* USER CODE BEGIN PFP */
static void poll_serial(void);
/* USER CODE END PFP */

/* USER CODE BEGIN 0 */
static char     cfg_msg[21];
static uint32_t cfg_msg_until = 0;
#define CFG_PAGE_MS 5000u
static uint32_t cfg_page_until = 0;

static void cfg_show(const char *s)
{
  strncpy(cfg_msg, s, sizeof(cfg_msg) - 1);
  cfg_msg[sizeof(cfg_msg) - 1] = '\0';
  cfg_msg_until = HAL_GetTick() + CFG_MSG_MS;
}

/* Window watchdog: may only be refreshed once the counter has dropped below Window
 * (~131 ms after the previous reload); refreshing earlier also resets the MCU.
 * Call it liberally everywhere — it ignores calls made before the window opens. */
void app_wwdg_kick(void)
{
  if (!wwdg_started) return;
  if ((hwwdg.Instance->CR & WWDG_CR_T) < hwwdg.Init.Window)
    HAL_WWDG_Refresh(&hwwdg);
}

/* The ONLY threshold comparison point — LEDs/LCD/Modbus STATUS all go through here */
static bool is_leak(int i)
{
  return vac_ch[i] >= 0 && vac_ch[i] * 1000.0f > (float)g_alert_mv;
}

/* Leakage ranks above a broken wire: a measured leakage voltage means the wire is connected. */
static ch_status_t ch_status(int i)
{
  if (!ch_enabled(i))                   return CH_DISABLED;
  if (vac_ch[i] < 0)                    return CH_ERR;
  if (is_leak(i))                       return CH_LEAK;
  if (wire_ch[i] == PROBE_OPEN)         return CH_WIRE_NG;
  if (wire_ch[i] == PROBE_UNKNOWN)      return CH_INIT;
  return CH_OK;
}

/* LEDs share a common anode, active LOW: pin RESET (pulled low) = on.
 * OK: green; leakage: red; wire broken: red heartbeat blink; ERR/INIT: both off. */
static void set_machine_led(int i, ch_status_t st)
{
#if LED_ENABLE
  g_green_on[i] = (st == CH_OK);
  g_red_on[i]   = (st == CH_LEAK);
  g_red_hb[i]   = (st == CH_WIRE_NG);
#else
  (void)i; (void)st;
#endif
}

/* Called from SysTick_Handler (1 kHz): updates the status LEDs.
 * Active-low LEDs (common anode, resistor-limited): RESET = on, SET = off.
 * Linux-style heartbeat for the red blink when the wire is broken. */
void app_led_pwm_tick(void)
{
#if LED_ENABLE
  static uint16_t hb = 0;
  if (++hb >= 1000) hb = 0;
  bool hb_on = (hb < 70) || (hb >= 170 && hb < 240);
  for (int i = 0; i < ADS_NUM_CHANNELS; i++) {
    bool red = g_red_on[i] || (g_red_hb[i] && hb_on);
    HAL_GPIO_WritePin(LED_G_PORT[i], LED_G_PIN[i], g_green_on[i] ? GPIO_PIN_RESET : GPIO_PIN_SET);
    HAL_GPIO_WritePin(LED_R_PORT[i], LED_R_PIN[i], red             ? GPIO_PIN_RESET : GPIO_PIN_SET);
  }
#endif
}

void app_rs485_poll_received(void) { last_rs485_poll = HAL_GetTick(); }

static bool    blink_state = false;
static uint32_t last_blink  = 0;


/* Layout (no header): 4 data rows + 1 ID row
 *  y=0  ───── outer border top
 *  y=1..12   M1 row (12px content)
 *  y=13 ───── divider
 *  y=14..25  M2 row
 *  y=26 ───── divider
 *  y=27..38  M3 row
 *  y=39 ───── divider
 *  y=40..51  M4 row
 *  y=52 ───── divider (above ID)
 *  y=53..62  ID row (10px, same as spec v2)
 *  y=63 ───── outer border bottom
 */
/* Append "<label><number>" to b at position n, return the new position */
static int fmt_label_u(char *b, int n, const char *label, uint32_t v)
{
  while (*label) b[n++] = *label++;
  char t[6];
  int  c = 0;
  do { t[c++] = (char)('0' + v % 10); v /= 10; } while (v);
  while (c) b[n++] = t[--c];
  b[n] = '\0';
  return n;
}

/* Settings page ("config" command): only the configured values, 5 rows */
static void lcd_show_settings(void)
{
  char b[17];
  int  n;
  lcd_draw_rect(0, 0, 128, 64, 1);

  n = fmt_label_u(b, 0, "ID:", g_cfg.device_id);
  n = fmt_label_u(b, n, " RS:", g_cfg.modbus_addr);
  lcd_draw_string(4, 3, b);

  n = fmt_label_u(b, 0, "THR:", g_cfg.alert_mv);
  n = fmt_label_u(b, n, " Qty:", g_cfg.ch_count);
  lcd_draw_string(4, 15, b);

  fmt_label_u(b, 0, "WIRE:", g_cfg.wire_mvpp);
  lcd_draw_string(4, 27, b);

  /* K×1000 — "K1:1000 K2:1000" matches how the kN= command displays it */
  n = fmt_label_u(b, 0, "K1:", (uint32_t)(kf(0) * 1000.0f + 0.5f));
  n = fmt_label_u(b, n, " K2:", (uint32_t)(kf(1) * 1000.0f + 0.5f));
  lcd_draw_string(4, 39, b);

  n = fmt_label_u(b, 0, "K3:", (uint32_t)(kf(2) * 1000.0f + 0.5f));
  n = fmt_label_u(b, n, " K4:", (uint32_t)(kf(3) * 1000.0f + 0.5f));
  lcd_draw_string(4, 51, b);
}

static void lcd_show_channels(bool any_alert)
{
  char buf[16];
  int i;
  lcd_clear();

  uint32_t now = HAL_GetTick();
  if (now - last_blink >= 500) {
    last_blink = now;
    blink_state = !blink_state;
  }

  if ((int32_t)(cfg_page_until - now) > 0) {
    lcd_show_settings();
    lcd_update();
    return;
  }

  lcd_draw_rect(0, 0, 128, 64, 1);

  lcd_draw_hline(0, 13, 128, 1);
  lcd_draw_hline(0, 26, 128, 1);
  lcd_draw_hline(0, 39, 128, 1);
  lcd_draw_hline(0, 52, 128, 1);

  lcd_draw_vline(28, 0, 53, 1);
  lcd_draw_vline(88, 0, 53, 1);

  static const int row_y[]  = {1, 14, 27, 40};
  static const int row_ye[] = {12, 25, 38, 51};

  for (i = 0; i < ADS_NUM_CHANNELS; i++) {
    int cy = row_y[i];
    int ty = cy + 2;

    if (!ch_enabled(i)) continue;        /* disabled channel: leave the row blank */

    lcd_draw_char(7, ty, 'P');
    lcd_draw_char(15, ty, (char)('1' + i));

    ch_status_t st = ch_status(i);
    if (vac_ch[i] < 0) {
      lcd_draw_string(32, ty, "----");
      lcd_draw_string(98, ty, "ERR");
    } else if (st == CH_WIRE_NG) {
      /* Wire broken: do not print 0.00V (easily mistaken for "no leakage"); both cells show
       * evenly spaced blinking 2x2 dots: voltage cell 29..87 5 dots every 12 px, status cell 89..126 4 dots every 9 px */
      if (blink_state) {
        for (int dx = 34; dx <= 82; dx += 12) lcd_fill_rect(dx, cy + 5, 2, 2, 1);
        for (int dx = 94; dx <= 121; dx += 9) lcd_fill_rect(dx, cy + 5, 2, 2, 1);
      }
    } else {
      int32_t s = (int32_t)(vac_ch[i] * 100.0f + 0.5f);
      if (s > 9999) s = 9999;
      int32_t ip = s / 100, fp = s % 100;
      int n = 0;
      if (ip >= 10) buf[n++] = (char)('0' + ip / 10);
      buf[n++] = (char)('0' + ip % 10);
      buf[n++] = '.';
      buf[n++] = (char)('0' + fp / 10);
      buf[n++] = (char)('0' + fp % 10);
      buf[n] = '\0';
      lcd_draw_string(32, ty, buf);
      lcd_draw_char(32 + n * 8, ty, 'V');

      const char *txt = st == CH_LEAK ? "NG" : st == CH_INIT ? "..." : "OK";
      if (st == CH_LEAK && blink_state) {
        lcd_fill_rect(89, cy, 38, row_ye[i] - cy + 1, 1);
        lcd_draw_string_inv(98, ty, txt);
      } else {
        lcd_draw_string(98, ty, txt);
      }
    }
  }

  /* ID row — 2-page alternating display */
  {
    if (now - last_page_switch >= LCD_PAGE_INTERVAL) {
      lcd_page = !lcd_page;
      last_page_switch = now;
    }

    if ((int32_t)(cfg_msg_until - now) > 0) {
      /* Config-command feedback, inverted to stand out, centred */
      int n = (int)strlen(cfg_msg);
      lcd_fill_rect(1, 53, 126, 10, 1);
      if (n <= 16) {
        lcd_draw_string_inv(64 - n * 4, 55, cfg_msg);
      } else {
        /* Long strings (5-command usage = 20 chars): 5 px glyphs drawn at 6 px pitch → 120 px */
        int x = 64 - n * 3;
        for (int k = 0; k < n; k++, x += 6) lcd_draw_char_inv(x, 55, cfg_msg[k]);
      }
    } else
    if (!lcd_page) {
      /* Page 1: ID:1001-RS:001 (14 chars, 112px, x=8) */
      uint16_t id = g_cfg.device_id;
      buf[0]  = 'I'; buf[1] = 'D';
      buf[2]  = blink_state ? ':' : ' ';
      buf[3]  = (char)('0' + (id / 1000) % 10);
      buf[4]  = (char)('0' + (id / 100) % 10);
      buf[5]  = (char)('0' + (id / 10) % 10);
      buf[6]  = (char)('0' + id % 10);
      buf[7]  = '-';
      buf[8]  = 'R'; buf[9] = 'S'; buf[10] = ':';
      buf[11] = (char)('0' + (g_cfg.modbus_addr / 100) % 10);
      buf[12] = (char)('0' + (g_cfg.modbus_addr / 10) % 10);
      buf[13] = (char)('0' + g_cfg.modbus_addr % 10);
      buf[14] = '\0';
      lcd_draw_string(8, 55, buf);
    } else {
      /* Page 2: LINK OK or OFFLINE M:SS */
      uint32_t elapsed = now - last_rs485_poll;
      bool offline = (elapsed > RS485_OFFLINE_MS);

      if (offline) {
        uint32_t secs = elapsed / 1000;
        uint32_t mm = secs / 60; if (mm > 9) mm = 9;
        uint32_t ss = secs % 60;
        buf[0] = 'O'; buf[1] = 'F'; buf[2] = 'F';
        buf[3] = 'L'; buf[4] = 'I'; buf[5] = 'N'; buf[6] = 'E'; buf[7] = ' ';
        buf[8] = (char)('0' + mm);
        buf[9] = ':';
        buf[10] = (char)('0' + ss / 10);
        buf[11] = (char)('0' + ss % 10);
        buf[12] = '\0';
        /* 12 chars = 96px → x=16 */
        lcd_fill_rect(1, 53, 126, 10, 1);
        lcd_draw_string_inv(16, 55, buf);
      } else {
        /* 7 chars = 56px → x=36 */
        lcd_draw_string(36, 55, "LINK OK");
      }
    }
  }

  (void)any_alert;
  lcd_update();
}

/* ---- Modbus RTU slave: 1-based register map, addr = channel number for clarity
 * (docs/rs485-modbus-protocol.md). Each channel's state is read from CH_STATUS —
 * there is no combined bitmap (it duplicated CH_STATUS). ----
 *  0    reserved (reads 0)
 *  1–4  V_AC channels P1–P4 (unit 0.01 V — matches LCD X.XX; I2C error → 0xFFFF, valid values clamp at 0xFFFE)
 *  5    DEVICE_ID                    6  ALERT_THRESHOLD mV (FC06 ghi, RAM-only)
 *  7    FW_HEARTBEAT                 8–11  CH_STATUS channels P1–P4 (ch_status_t)
 *  12–15 WIRE_MVPP channels P1–P4 (wire-check amplitude)
 *  16   WIRE_THRESHOLD (wire-break threshold shared by 4 channels, read-only)
 *  17   CH_COUNT 1..4 (channels in the group, writable via FC06 — like qty=, saved to flash;
 *       disabled channel: VAC=0, CH_STATUS=5, WIRE_MVPP=0) */
static uint16_t mb_app_reg_read(uint16_t addr)
{
  switch (addr) {
  case 1: case 2: case 3: case 4: {
    int i = addr - 1;
    if (!ch_enabled(i)) return 0;                  /* disabled channel (qty=) — CH_STATUS = 5 */
    if (vac_ch[i] < 0) return 0xFFFF;              /* I2C error — before any conversion */
    uint32_t cv = (uint32_t)(vac_ch[i] * 100.0f + 0.5f);   /* 0.01 V/LSB */
    return (cv > 0xFFFE) ? 0xFFFE : (uint16_t)cv;
  }
  case 5: return g_cfg.device_id;
  case 6: return g_alert_mv;
  case 7: return mb_heartbeat;
  case 8: case 9: case 10: case 11:
    return (uint16_t)ch_status(addr - 8);
  case 12: case 13: case 14: case 15:
    return wire_mvpp[addr - 12];
  case 16: return g_cfg.wire_mvpp;                 /* wire-break threshold (read-only; set with wire=) */
  case 17: return g_cfg.ch_count;                  /* channels in the group (qty= command) */
  default: return 0;                               /* addr 0 reserved; the core rejects addr ≥ MB_REG_COUNT */
  }
}

static void cfg_save_show(const char *label, uint32_t v)
{
  app_wwdg_kick();
  bool saved = config_save(&g_cfg);
  app_wwdg_kick();
  char m[20];
  int  n = 0;
  while (label[n]) { m[n] = label[n]; n++; }
  char tmp[6];
  int  t = 0;
  do { tmp[t++] = (char)('0' + v % 10); v /= 10; } while (v);
  while (t) m[n++] = tmp[--t];
  m[n] = '\0';
  strcat(m, saved ? " SAVED" : " FLASH!");
  cfg_show(m);
}

/* FC06 can write 2 registers:
 *  - 6  ALERT_THRESHOLD: RAM-only — the persistent value lives in flash (thr= command);
 *       a master that wants its own threshold re-writes it on every poll
 *  - 17 CH_COUNT: like the qty= UART2 command — saved to flash, applied on the next scan */
static mb_wr_result_t mb_app_reg_write(uint16_t addr, uint16_t val)
{
  switch (addr) {
  case 6:
    if (val < 100 || val > 60000) return MB_WR_BAD_VALUE;
    g_alert_mv = val;
    return MB_WR_OK;
  case 17:
    if (val < 1 || val > ADS_NUM_CHANNELS) return MB_WR_BAD_VALUE;
    g_cfg.ch_count = (uint8_t)val;       /* next scan: channels > val are skipped, data cleared */
    cfg_save_show("QTY:", val);          /* write flash + LCD feedback, same path as qty= */
    return MB_WR_OK;
  default:
    return MB_WR_BAD_ADDR;
  }
}

static const mb_port_t MB_PORT = {
  .get_tick_ms = HAL_GetTick,
  .tx_start    = mb_port_usart1_tx_start,
  .tx_busy     = mb_port_usart1_tx_busy,
  .reg_read    = mb_app_reg_read,
  .reg_write   = mb_app_reg_write,
  .on_reply_ok = app_rs485_poll_received,
};

void app_comm_poll(void) {
  mb_poll();
}

/* ---- Config commands over USART2 RX (no TX — result shown on the LCD for 3 s):
 * id=<1..9999> | addr=<1..247> | thr=<100..60000> (mV) | wire=<100..3000> (mVpp)
 * | qty=<1..4> (channel count) | v=<500..24000> (reference mV being applied → calibrate K on all 4 channels)
 * | k1=..k4=<500..24000> (calibrate K on one channel). Saved to flash immediately.
 * | config (no argument): show the settings page for 5 s. ---- */

/* Case-insensitive prefix match; returns a pointer past the prefix or NULL */
static const char *cmd_prefix(const char *p, const char *kw)
{
  while (*kw) {
    char c = *p, k = *kw;
    if (c >= 'A' && c <= 'Z') c = (char)(c - 'A' + 'a');
    if (c != k) return NULL;
    p++; kw++;
  }
  return p;
}

/* Parse a decimal number; -1 if empty or containing invalid characters */
static int32_t cmd_num(const char *d)
{
  if (*d < '0' || *d > '9') return -1;
  int32_t v = 0;
  for (; *d >= '0' && *d <= '9'; d++) {
    v = v * 10 + (*d - '0');
    if (v > 100000) return -1;
  }
  return (*d == '\0') ? v : -1;
}
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
int main(void)
{

  /* MCU Configuration--------------------------------------------------------*/

  /* Reset of all peripherals, Initializes the Flash interface and the Systick. */
  HAL_Init();

  /* Configure the system clock */
  SystemClock_Config();

  /* Initialize all configured peripherals */
  MX_GPIO_Init();
  MX_I2C1_Init();
  MX_SPI1_Init();
  MX_USART1_UART_Init();
  MX_USART2_UART_Init();
  MX_WWDG_Init();
  MX_ADC1_Init();
  MX_TIM1_Init();
  MX_TIM3_Init();
  /* USER CODE BEGIN 2 */
  APP_LOG_INIT();
#if APP_DEBUG
  /* J-Link halts the core (flashing, RTT attach) but the WWDG keeps counting → spurious WWDG reset.
   * Freeze the WWDG while the core is halted; not needed in production. */
  __HAL_RCC_DBGMCU_CLK_ENABLE();
  __HAL_DBGMCU_FREEZE_WWDG();
#endif
  wwdg_started = true;

  /* Load config from flash (if present); V conversion uses the static calibration table in ads1015.c */
  bool cfg_loaded = config_load(&g_cfg);
  g_alert_mv = g_cfg.alert_mv;
  probe_set_open_mvpp(g_cfg.wire_mvpp);

  /* Modbus RTU slave on USART1: core + bare-register port.
   * From here on, no HAL UART TX API may be used on huart1 (one UART, one owner). */
  mb_init(&MB_PORT, g_cfg.modbus_addr, MB_REG_COUNT);
  mb_port_usart1_init();

  APP_LOG("[boot] id=%u addr=%u thr=%umV cfg=%s rst=%s%s%s%s\r\n",
          g_cfg.device_id, g_cfg.modbus_addr, g_alert_mv, cfg_loaded ? "flash" : "defaults",
          __HAL_RCC_GET_FLAG(RCC_FLAG_PWRRST)  ? "POR "  : "",
          __HAL_RCC_GET_FLAG(RCC_FLAG_PINRST)  ? "PIN "  : "",
          __HAL_RCC_GET_FLAG(RCC_FLAG_SFTRST)  ? "SFT "  : "",
          __HAL_RCC_GET_FLAG(RCC_FLAG_WWDGRST) ? "WWDG " : "");
  __HAL_RCC_CLEAR_RESET_FLAGS();

  lcd_init();
  app_wwdg_kick();
  APP_LOG("[boot] lcd_init ok\r\n");
  probe_init();
  app_wwdg_kick();
  /* USER CODE END 2 */

  /* Infinite loop */
  /* USER CODE BEGIN WHILE */
  while (1)
  {
    /* USER CODE END WHILE */

    /* USER CODE BEGIN 3 */
    mb_poll();
    static uint32_t last_print = 0;
    bool any_alert = false;
    ads_meas_t m;

    for (int i = 0; i < ADS_NUM_CHANNELS; i++) {
      poll_serial();
      mb_poll();
      app_wwdg_kick();

      if (!ch_enabled(i)) {
        /* Disabled channel: clear old data (qty= changed at runtime), LED off, no measurement */
        vac_ch[i] = 0.0f; raw_ch[i] = 0.0f; vac_uncal[i] = 0.0f;
        wire_ch[i] = PROBE_UNKNOWN; wire_mvpp[i] = 0;
        set_machine_led(i, CH_DISABLED);
        continue;
      }

      /* Check the wire before every measurement, regardless of the previous result. */
      probe_result_t pr;
      if (probe_measure(i, &pr)) {
        wire_ch[i]   = probe_update(i, &pr);
        wire_mvpp[i] = pr.mvpp;
      } else {
        APP_LOG("[probe] P%d ADC error\r\n", i + 1);
      }
      HAL_Delay(PROBE_SETTLE_MS);
      app_wwdg_kick();

      bool ok = ads_measure_channel(&hi2c1, i, &m);
      vac_uncal[i] = ok ? m.vac : 0.0f;
      vac_ch[i] = ok ? m.vac * kf(i) : -1.0f;   /* -1 = IC not responding */
      raw_ch[i] = ok ? m.vrms_total : 0.0f;
      if (ok && vac_ch[i] < VAC_ZERO_V) vac_ch[i] = 0.0f;
      if (!ok) APP_LOG("[i2c] P%d not responding\r\n", i + 1);


      ch_status_t st = ch_status(i);
      if (st == CH_LEAK || st == CH_WIRE_NG) any_alert = true;
      set_machine_led(i, st);
      app_wwdg_kick();
    }
    mb_heartbeat++;

    /* PA0 (label D0) is the LCD A0 pin — no longer used as a global alert output */

    /* Print results + update the LCD every 1 s (a 4-channel scan takes ~820 ms) */
    uint32_t now = HAL_GetTick();
    if (now - last_print >= PRINT_INTERVAL_MS) {
      last_print = now;
      lcd_show_channels(any_alert);
      app_wwdg_kick();
      mb_poll();
      /* RTT has no %f: print mV (vac*1000), -1 = channel error */
      APP_LOG("[meas] P1=%d P2=%d P3=%d P4=%d mV | %s, %s, %s, %s (%u %u %u %u mVpp)%s\r\n",
          (int)(vac_ch[0] * 1000.0f), (int)(vac_ch[1] * 1000.0f),
          (int)(vac_ch[2] * 1000.0f), (int)(vac_ch[3] * 1000.0f),
          probe_state_str(wire_ch[0]), probe_state_str(wire_ch[1]),
          probe_state_str(wire_ch[2]), probe_state_str(wire_ch[3]),
          (unsigned)wire_mvpp[0], (unsigned)wire_mvpp[1],
          (unsigned)wire_mvpp[2], (unsigned)wire_mvpp[3],
          any_alert ? " ALERT" : "");
    }
    app_wwdg_kick();
  }
  /* USER CODE END 3 */
}

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


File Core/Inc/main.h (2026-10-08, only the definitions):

#define IN1_IC3_Pin GPIO_PIN_15
#define IN1_IC3_GPIO_Port GPIOC
#define D0_Pin GPIO_PIN_0
#define D0_GPIO_Port GPIOA
#define ADC1_IN5_NO1_Pin GPIO_PIN_5
#define ADC1_IN5_NO1_GPIO_Port GPIOA
#define IN1_IC4_Pin GPIO_PIN_6
#define IN1_IC4_GPIO_Port GPIOA
#define ADC1_IN7_NO2_Pin GPIO_PIN_7
#define ADC1_IN7_NO2_GPIO_Port GPIOA
#define ADC1_IN17_NO3_Pin GPIO_PIN_0
#define ADC1_IN17_NO3_GPIO_Port GPIOB
#define ADC1_IN18_NO4_Pin GPIO_PIN_1
#define ADC1_IN18_NO4_GPIO_Port GPIOB
#define IN1_IC2_Pin GPIO_PIN_6
#define IN1_IC2_GPIO_Port GPIOC
#define L_GREEN4_Pin GPIO_PIN_10
#define L_GREEN4_GPIO_Port GPIOA
#define L_RED4_Pin GPIO_PIN_11
#define L_RED4_GPIO_Port GPIOA
#define IN1_IC1_Pin GPIO_PIN_15
#define IN1_IC1_GPIO_Port GPIOA
#define L_GREEN3_Pin GPIO_PIN_3
#define L_GREEN3_GPIO_Port GPIOB
#define L_RED3_Pin GPIO_PIN_4
#define L_RED3_GPIO_Port GPIOB
#define L_GREEN2_Pin GPIO_PIN_5
#define L_GREEN2_GPIO_Port GPIOB
#define L_RED2_Pin GPIO_PIN_6
#define L_RED2_GPIO_Port GPIOB
#define L_GREEN1_Pin GPIO_PIN_7
#define L_GREEN1_GPIO_Port GPIOB
#define L_RED1_Pin GPIO_PIN_8
#define L_RED1_GPIO_Port GPIOB

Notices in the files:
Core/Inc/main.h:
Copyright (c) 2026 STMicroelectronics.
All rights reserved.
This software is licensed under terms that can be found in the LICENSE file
